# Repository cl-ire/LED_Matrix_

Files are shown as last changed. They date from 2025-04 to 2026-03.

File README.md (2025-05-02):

# LED NeoPixel Matrix Controller with Raspberry Pi Pico W2

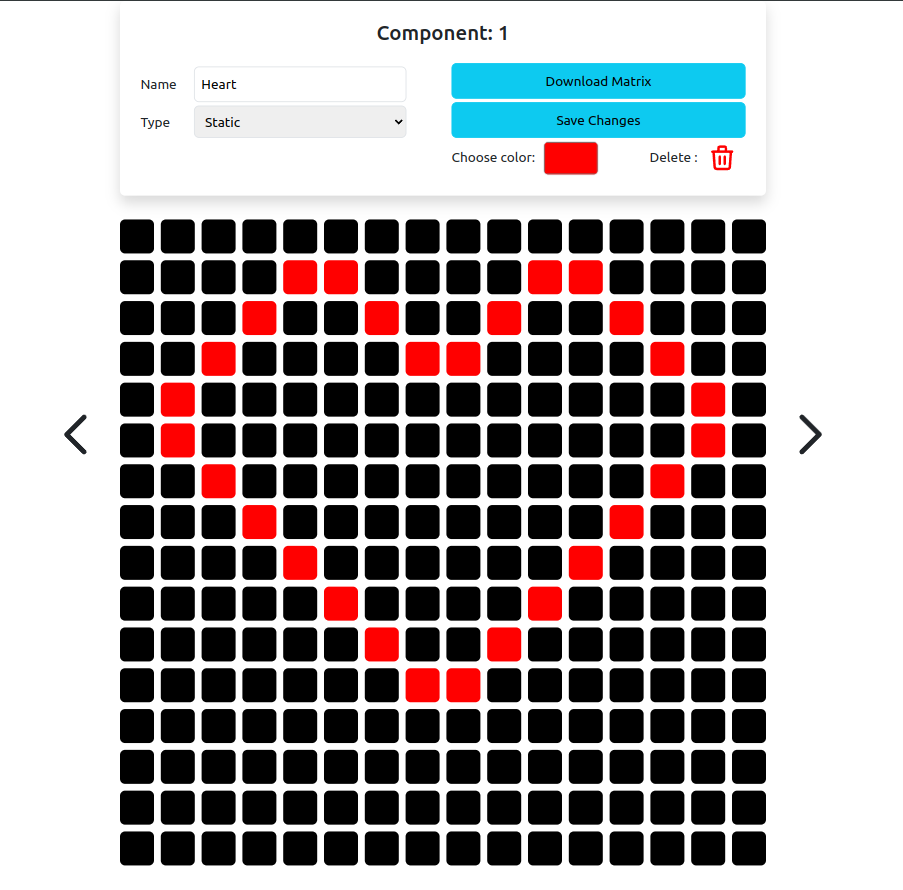
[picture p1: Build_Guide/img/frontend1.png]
frontend


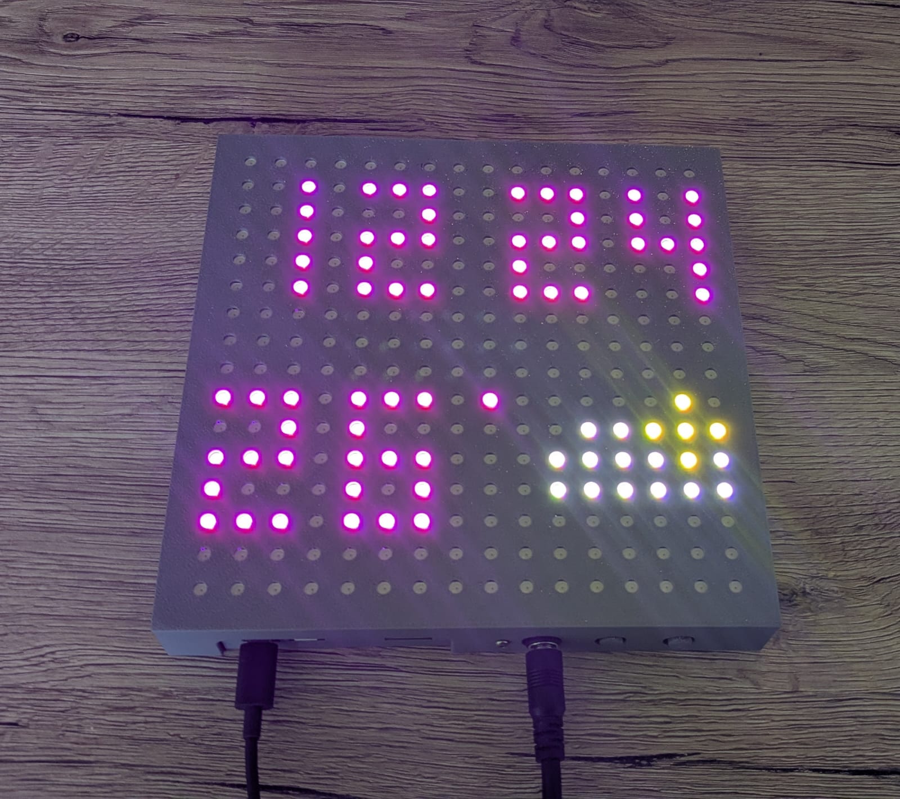
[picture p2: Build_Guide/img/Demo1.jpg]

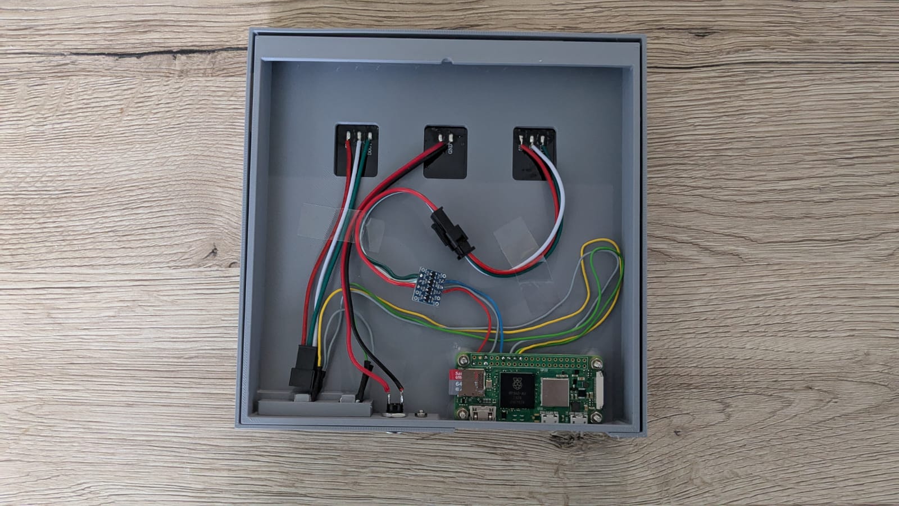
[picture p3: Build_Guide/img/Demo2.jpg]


This project allows you to control a 16x16 LED NeoPixel matrix using a Raspberry Pi Pico W2. 

## Features:
- Control LED matrix displays through a web interface
- Pixel art editor to create static and animated images
- Interact with GPIO buttons on the Raspberry Pi to control the matrix
- Backend API to communicate with the NeoPixel matrix
- Fully containerized using Docker for seamless deployment

## Components
- Raspberry Pi Pico W2
- Micro SD Card 
- 16x16 LED Matrix ( [build with BTF-LIGHTING WS2812BECO](https://www.amazon.de/dp/B088K1JH6X?ref=ppx_yo2ov_dt_b_fed_asin_title&th=1) )
- I2C Logic Level Converter 3.3V to 5V
- 2 Push Buttons
- DC Power Jack 5,5mm x 2,1mm ( [build with](https://www.amazon.de/dp/B08HGXYS4J?ref=ppx_yo2ov_dt_b_fed_asin_title) )
- Power Supply 5V 15A ( [build with ALITOVE Netzteil 5V 15A Universal Adapter 5 Volt Netzteil 75W](https://www.amazon.de/dp/B0B49ZN1LF?ref=ppx_yo2ov_dt_b_fed_asin_title&th=1) )

## Build Guide 

### Print the Case 

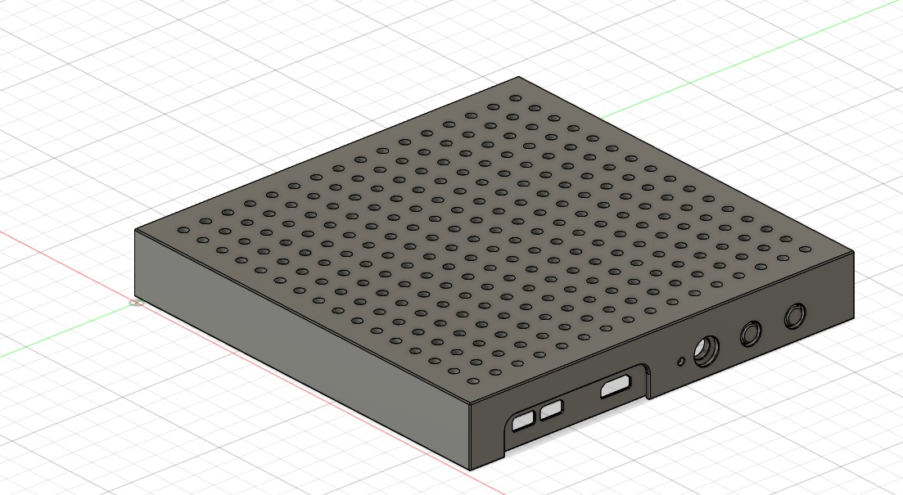
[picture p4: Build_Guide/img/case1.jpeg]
case1

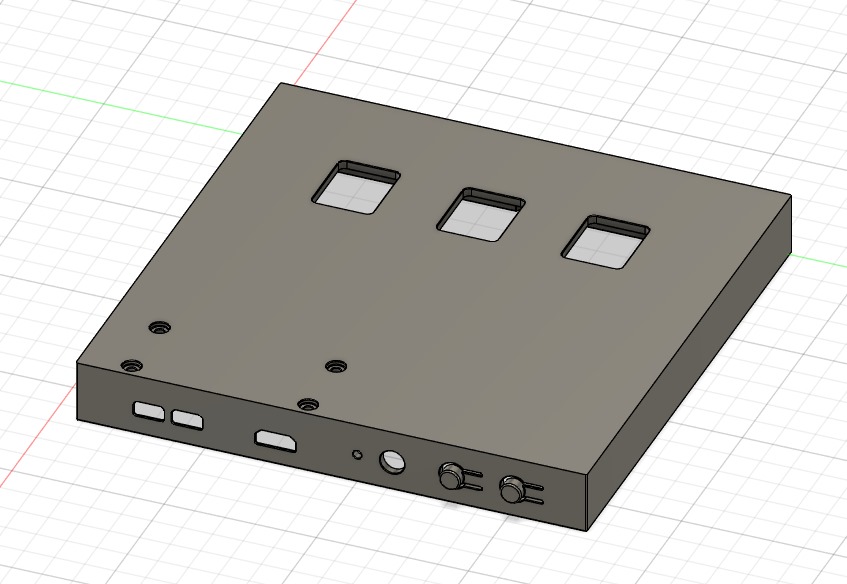
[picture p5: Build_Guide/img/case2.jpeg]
case2

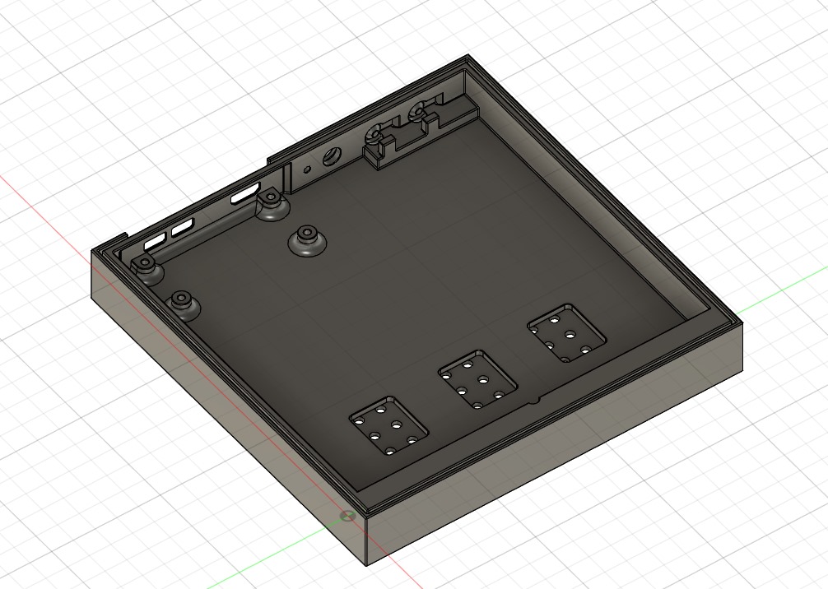
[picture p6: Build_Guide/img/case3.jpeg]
case3


The STEP files for the case are provided [here](./Build_Guide/step/)

### Wiring 

Wire up all the components according to the following diagram:

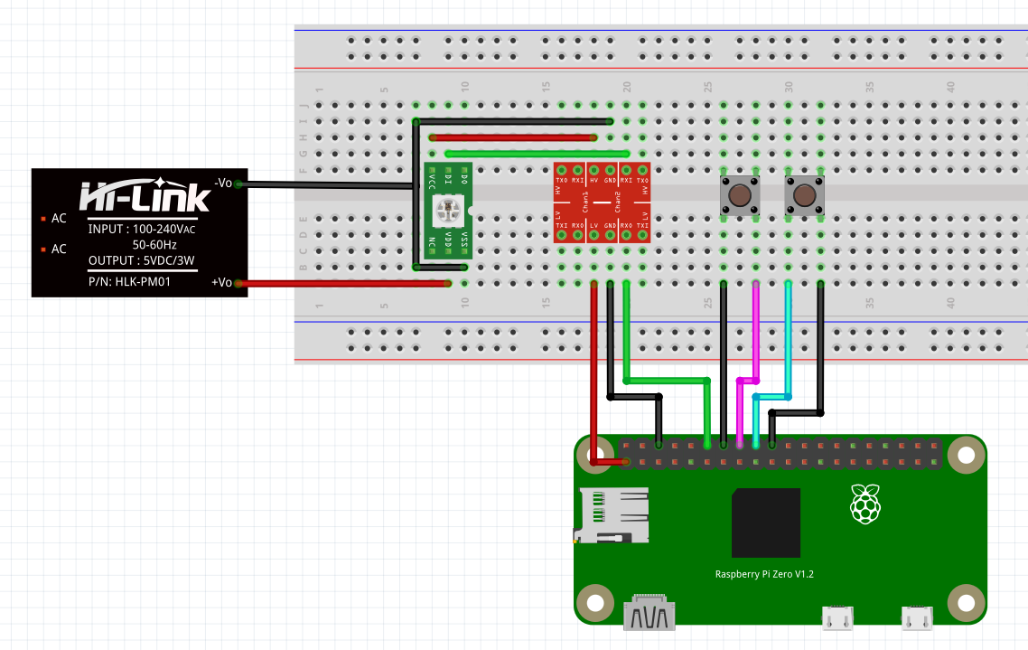
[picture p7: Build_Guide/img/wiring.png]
wiring


Some LED matrices have a dedicated power input — if available, use it.

Make sure the wires are routed through the case before connecting the DC power jack.

Tape the matrix to the case with double-sided tape and secure the buttons in place

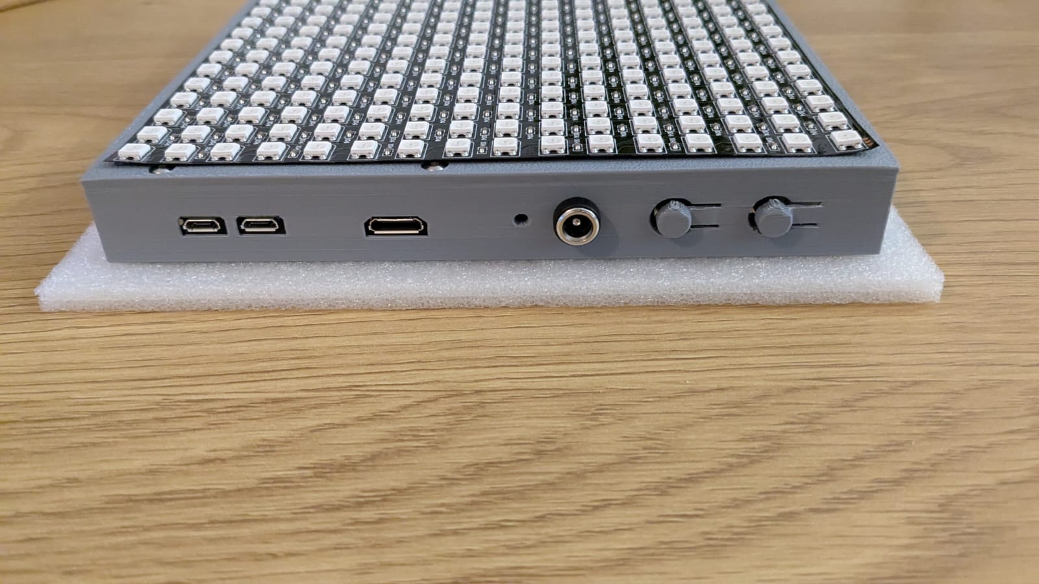
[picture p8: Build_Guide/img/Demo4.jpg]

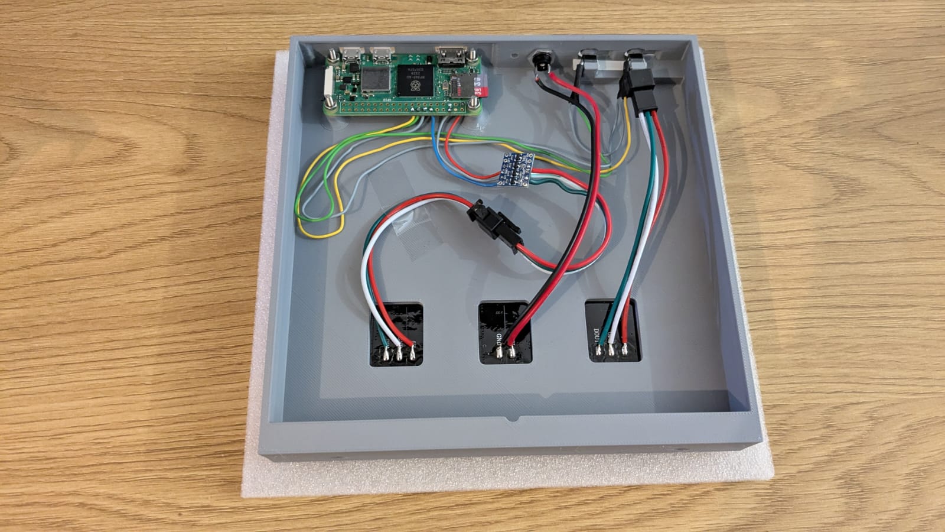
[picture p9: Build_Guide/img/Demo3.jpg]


### Note About Matrix Choice

The LED matrix used in this example functions like a light strip, so the LEDs need to be addressed as an array according to the following scheme:

```bash
2 1 0 
3 4 5
8 7 6
```

If you want to use a different matrix, you might need to adapt the `get_index` function in [LEDMatrix](./src/backend/LEDMatrix/LEDMatrix.py)

## Installation Guide

### Installing Ubuntu Server 22.04.3 LTS (64-bit) on Raspberry Pi

Download and install the official Raspberry Pi Imager from (https://www.raspberrypi.com/software).
Choose the following parameters:

- Operating System: `Other general-purpose OS/Ubuntu/Ubuntu Server 22.04.3 LTS (32-bit)`.

in the Advanced Options Menu

- Set hostname: LED_Matrix
- Enable SSH with pasword authentication 
- Username: led
- Password: <pw>
- Configure a wireles LAN

### Connect Over SSH

In your command line, type:

```bash
ssh led@<your-ip-adress>
```

Then enter your password.

### Install Docker 

Install dependencies:
```bash
sudo apt install apt-transport-https ca-certificates curl software-properties-common
```

Add Docker’s official GPG key:
```bash
curl -fsSL https://download.docker.com/linux/ubuntu/gpg | sudo gpg --dearmor -o /usr/share/keyrings/docker-archive-keyring.gpg
```

Add Docker repository:
```bash
echo "deb [arch=$(dpkg --print-architecture) signed-by=/usr/share/keyrings/docker-archive-keyring.gpg] https://download.docker.com/linux/ubuntu $(lsb_release -cs) stable" | sudo tee /etc/apt/sources.list.d/docker.list > /dev/null
```

Update:
```bash
sudo apt update
```

Install Docker:
```bash
sudo apt install docker-ce
sudo apt install docker-compose-plugin
```

Varify instalation:
```bash
docker --version
docker-compose --version
```

Enable Docker to start on boot:
```bash
sudo systemctl enable docker

```

Add the User to the Docker Group
```bash
sudo usermod -aG docker led  
logout
groups
```

### Set firewal rules 

```bash
sudo apt install ufw
sudo ufw enable
```

```bash
sudo ufw allow 80/tcp
sudo ufw allow 8000/tcp
sudo ufw status
```

### Start the Container

First, configure the `.env` file:

```bash
cd ~/LED_Matrix_/src/Docker/
nano .env
```

Add the following lines:

```bash
# .env file
LATITUDE=
LONGITUDE=
TZ=Europe/Berlin  # Optional timezone setting
MATRIX_ROTATION=90   # set rotation to 0, 90, 180, 270
SWAP_BUTTONS="true"  # Swaps buttons "true" or "false"
```

Start the container:
```bash
cd ~/LED_Matrix_/src/Docker/
docker compose up -d
```

Now you can access the application at:

http://LED_Matrix.local

### additional comands 

Stop the container:
```bash
cd ~/LED_Matrix_/src/Docker/
docker compose down
```

Rebuild the container:
```bash
cd ~/LED_Matrix_/src/Docker/
docker compose build
docker compose up -d
```

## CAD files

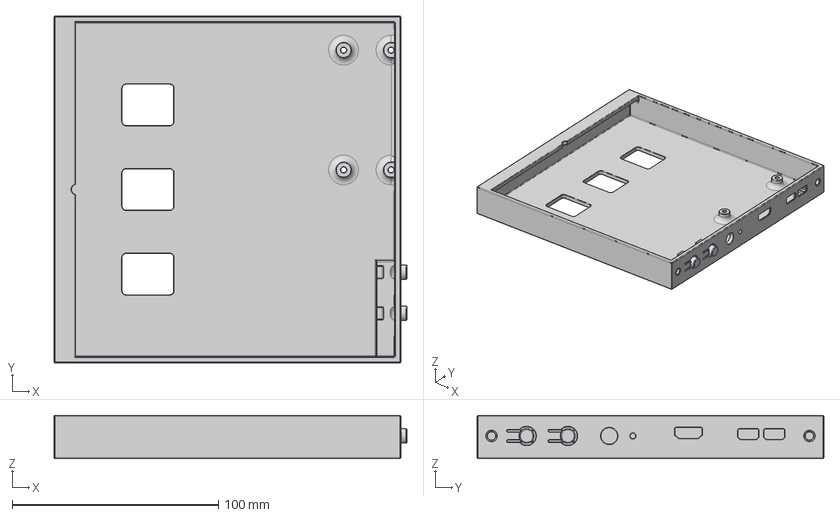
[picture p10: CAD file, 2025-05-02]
Build_Guide/step/Bottom.step
171.0 x 168.0 x 21.0 mm

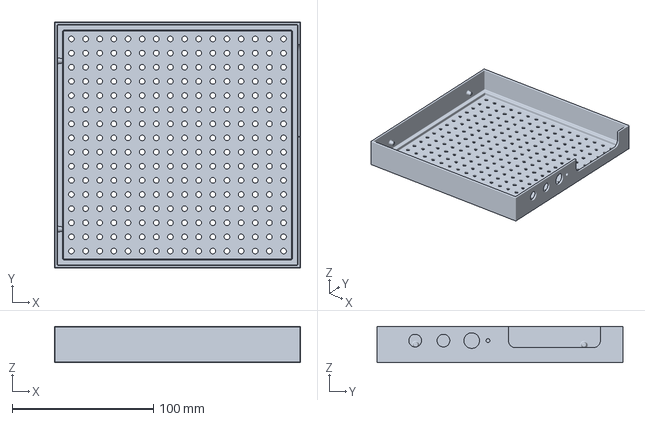
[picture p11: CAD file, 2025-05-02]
Build_Guide/step/Lid.3mf
174.0 x 174.0 x 25.5 mm

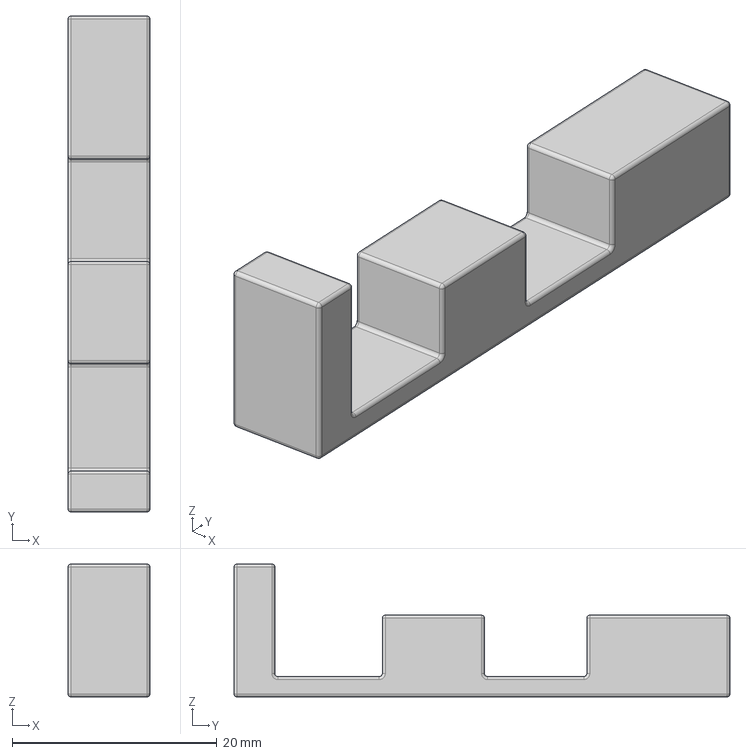
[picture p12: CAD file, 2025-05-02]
Build_Guide/step/Button_Cover.step
8.00 x 48.5 x 13.0 mm

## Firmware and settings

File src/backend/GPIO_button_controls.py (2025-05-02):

import asyncio
import time
import threading
import os
import board
import digitalio
from adafruit_debouncer import Debouncer

swap_buttons = os.getenv("SWAP_BUTTONS")

# BUTTON PINS
BUTTON_INC = 23  # GPIO pin to increase index
BUTTON_DEC = 24  # GPIO pin to decrease index

# Function to setup GPIO and pass callback function
def setup_gpio(change_index):
    
    if swap_buttons == "true":
        inc_pin = digitalio.DigitalInOut(board.D24)
        dec_pin = digitalio.DigitalInOut(board.D23)
    else:
        inc_pin = digitalio.DigitalInOut(board.D23)
        dec_pin = digitalio.DigitalInOut(board.D24)
    
    
    inc_pin.direction = digitalio.Direction.INPUT
    inc_pin.pull = digitalio.Pull.UP
    inc_button = Debouncer(inc_pin)

    dec_pin.direction = digitalio.Direction.INPUT
    dec_pin.pull = digitalio.Pull.UP
    dec_button = Debouncer(dec_pin)

    # Start the button monitoring thread
    button_thread = threading.Thread(target=button_monitoring_loop, args=(inc_button, dec_button, change_index))
    button_thread.daemon = True  # This ensures the thread will close when the main program exits
    button_thread.start()

# The function to run the button checking in a separate thread
def button_monitoring_loop(inc_button, dec_button, change_index):
    while True:
        # Update debouncers
        inc_button.update()
        dec_button.update()

        # Check if the button was pressed
        if inc_button.fell:
            handle_increase(change_index)

        if dec_button.fell:
            handle_decrease(change_index)

        # Small delay to prevent high CPU usage
        time.sleep(0.01)

# Handle increase button press
def handle_increase(change_index):
    # Using asyncio to run the async function in a proper way
    asyncio.run(button_change_index(1, change_index))

# Handle decrease button press
def handle_decrease(change_index):
    # Using asyncio to run the async function in a proper way
    asyncio.run(button_change_index(-1, change_index))

# Function to change index in a separate thread
async def button_change_index(delta: int, change_index):
    await change_index(delta)

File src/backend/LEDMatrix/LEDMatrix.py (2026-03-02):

import time
import board
import neopixel
import threading
import os

from .digits import digits, weather_symbols
from .time_api import get_current_time
from .weather_api import get_weather
from .system_time_api import get_system_time

latitude = os.getenv("LATITUDE")
longitude = os.getenv("LONGITUDE")
timezone = os.getenv("TZ")

matrix_rotation = os.getenv("MATRIX_ROTATION")
brightness = float(os.getenv("BRIGHTNESS", "0.2"))
clock_start_hour = int(os.getenv("CLOCK_START_HOUR", "7"))
clock_end_hour = int(os.getenv("CLOCK_END_HOUR", "24"))

class LEDMatrix:
    def __init__(self, rows, cols):
        self.brightness = brightness
        self.rows = rows
        self.cols = cols
        self.matrix = [[(0,0,0) for _ in range(cols)] for _ in range(rows)]
        self.clock_active = False
        self.clock_thread = None
        
        self.animation_active = False
        self.animation_thread = None
        
        pixel_pin = board.D18
        self.num_pixels = rows * cols
        
        self.pixels = neopixel.NeoPixel(pixel_pin, self.num_pixels, brightness=self.brightness, auto_write=False)

    def set_pixel(self, x, y, r, g, b):
        if 0 <= x < self.cols and 0 <= y < self.rows:
            self.pixels[self.get_index(x,y)] = (r, g, b)
    
    def fill_matrix(self, r, g, b):
        self.pixels.fill((r, g, b))
        self.pixels.show()
    
    def get_index(self, x, y):
        if 0 <= x < self.cols and 0 <= y < self.rows:
            
            if matrix_rotation == "0":            
                if y % 2 == 0:
                    return y * self.cols + (self.cols - x - 1)
                else:
                    return y * self.cols + x
            elif matrix_rotation == "90":    # 90 degrees counter-clockwise
                original_x = self.rows - y - 1
                original_y = x
                if original_y % 2 == 0:
                    return original_y * self.cols + (self.cols - original_x - 1)
                else:
                    return original_y * self.cols + original_x
            elif matrix_rotation == "180":    # 180 degrees
                flipped_x = self.cols - 1 - x
                flipped_y = self.rows - 1 - y
                if flipped_y % 2 == 0:
                    return flipped_y * self.cols + (self.cols - 1 - flipped_x)
                else:
                    return flipped_y * self.cols + flipped_x
            elif matrix_rotation == "270":    # 270 degrees counter-clockwise
                original_x = y
                original_y = self.cols - 1 - x

                if original_y % 2 == 0:
                    return original_y * self.cols + (self.cols - 1 - original_x)
                else:
                    return original_y * self.cols + original_x
        return None
        
    def load_matrix(self, matrix):
        for y in range(self.rows):
            for x in range(self.cols):
                self.pixels[self.get_index(x, y)] = matrix[y][x]
        self.pixels.show()    
     
    def clear(self):
        self.pixels.fill((0, 0, 0))
        self.pixels.show()
    
    def process_number(self, number):
        n_positiv = True
        if number is None:
            print("Error: Number is None")
            return 0, 0, 0
        
        if number < 0:
            n_positiv = False
            number = abs(number)
        
        if number < 10:
            return 0, number, n_positiv
        else:
            # Split the digits of the number
            n_digits = [int(n_digit) for n_digit in str(number)]
            return n_digits[0], n_digits[1], n_positiv
    
    def place_digit(self, digit, x, y, color=[170,0,170]):
        matrix = digits[str(digit)]
        for i in range(5):
            for j in range(3):
                val = matrix[i][j]
                if 0 <= y + i < self.rows and 0 <= x + j < self.cols:                    
                    if val == 1:
                        self.set_pixel(x + j, y + i, color[0], color[1], color[2]) 
                    else: 
                        self.set_pixel(x + j, y + i, 0, 0, 0)
    
    def place_weather(self, weather, x, y):
        matrix = weather_symbols[weather]
        for i in range(6):
            for j in range(6):
                val = matrix[i][j]
                if 0 <= y + i < self.rows and 0 <= x + j < self.cols:                    
                    self.set_pixel(x + j, y + i, matrix[i][j][0], matrix[i][j][1], matrix[i][j][2])
    
    def place_clock(self, hour, minute, temp, weather, color=[170,0,170]):
        
        if (isinstance(hour, (int)) and isinstance(minute, (int)) and isinstance(temp, (int)) and weather in weather_symbols):       
        
            hour_1, hour_2, n_hour = self.process_number(hour)
            
            self.place_digit(hour_1, 0, 1)
            self.place_digit(hour_2, 4, 1)

            minute_1, minute_2, n_minute = self.process_number(minute)
            
            self.place_digit(minute_1, 9, 1)
            self.place_digit(minute_2, 13, 1)
            
            temp_1, temp_2, n_temp = self.process_number(temp)

            if n_temp:        
                if temp_1 != 0:
                    self.place_digit(temp_1, 0, 9)
                else:
                    self.place_digit("blank", 0, 9)
                self.place_digit(temp_2, 4, 9)        
                self.set_pixel(8, 9, color[0], color[1], color[2]) # colon
            else:
                if temp_1 != 0 and temp_1 != 1:
                    self.place_digit(temp_1, 2, 9)
                    self.place_digit(temp_2, 6, 9)        
                    self.set_pixel(0, 11, color[0], color[1], color[2]) # minus sign
                    self.set_pixel(8, 9, color[0], color[1], color[2])  # colon
                elif temp_1 == 1:
                    self.place_digit(temp_1, 0, 9)
                    self.place_digit(temp_2, 4, 9)
                    self.set_pixel(0, 11, color[0], color[1], color[2]) # minus sign
                    self.set_pixel(8, 9, color[0], color[1], color[2])  # colon
                else:
                    self.place_digit(temp_2, 4, 9)
                    self.set_pixel(0, 11, color[0], color[1], color[2]) # minus sign
                    self.set_pixel(1, 11, color[0], color[1], color[2]) # minus sign
                    self.set_pixel(2, 11, color[0], color[1], color[2]) # minus sign
            
            self.place_weather(weather, 10, 9)

            self.pixels.show()
        else:
            print("Error: Invalid parameters for place_clock")
            print(f"hour: {hour}, minute: {minute}, temp: {temp}, weather: {weather}")
            
        
    def update_clock(self):
        counter = 0
        self.clear()
        last_temperature = 0
        last_weather = "clear"
        while self.clock_active:
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

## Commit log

2025-04-28 LED Matrix
    [LED_Matrix.fzz]
2025-05-02 added step files and matrix rotation
    [Bottom.step, Button_Cover.step, Lid.3mf]
2025-05-02 addes images and button swap config
    [GPIO_button_controls.py, LEDMatrix.py]
2026-03-02 temp transition fix 1
    [digits.py]
2026-03-02 temp transition fix 2
    [LEDMatrix.py]
2026-03-02 temp transition fix 3
    [LEDMatrix.py]
